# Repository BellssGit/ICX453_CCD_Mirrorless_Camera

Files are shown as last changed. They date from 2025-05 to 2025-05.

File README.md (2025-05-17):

# DIY APS-C Size CCD Sensor Mirrorless Camera



Blog about this project: https://www.emoe.xyz/diy_ccd_camera/ (Chinese)

or https://www.bilibili.com/read/cv41529294/ (Chinese)

## Hardware

1. FPGA Core board --- [Open source ZYNQ7000 Board from oshwhub.com](https://oshwhub.com/z_star/zynq7020-core-board-and-various-rf-modules)
2. CCD Base board --- "CCD_Sensor_ZYNQ_Based_Board" Folder (KiCAD >= 8)
3. Handle and Lens Mount --- "3d_model" Folder (FreeCAD >= 1.0)

## Software

1. "pixel_rearrange.py" for pixel re-arrangement
2. GIMP for gamma correction
3. Fitswork4 for debayer 
4. Photoshop and the "CCD_CameraRAW_Preset" for color grading
5. Vivado 2018.3 and "CCD_Cam_Vivado_workspace.7z" for both PL and PS source code

   Note: Due to Github file size limitation and I dont want to upload the whole workspace folder (because that is a mess), So the workspace is split into two smaller compressed files.

   Update: Just realized I miss a verilog source file "line_skipper.v" which lead to a compile error when generating bitstream. Now the file is in the repo, this is a easy fix. Have fun :)

Some sample photo





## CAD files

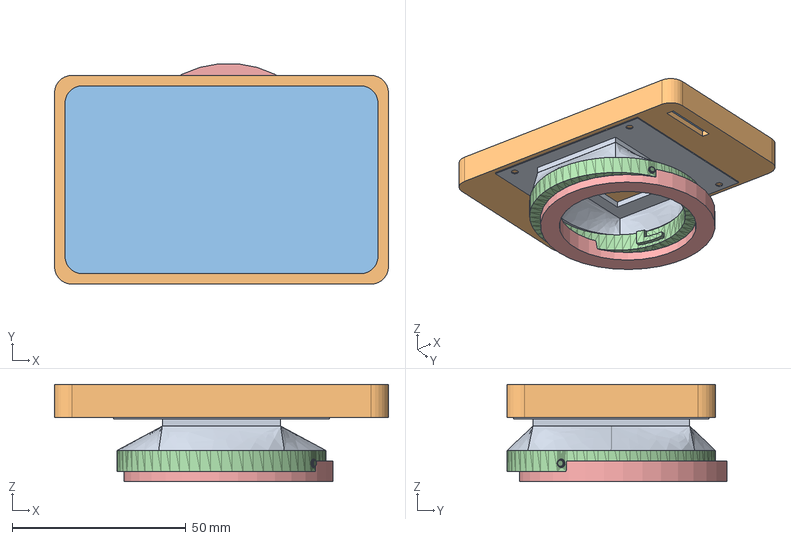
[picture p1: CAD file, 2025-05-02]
3d_model/CCD_Lensmount.FCStd
96.0 x 63.3 x 28.0 mm
top_cover
true_butt
PCB
lens_mount
ring_bump

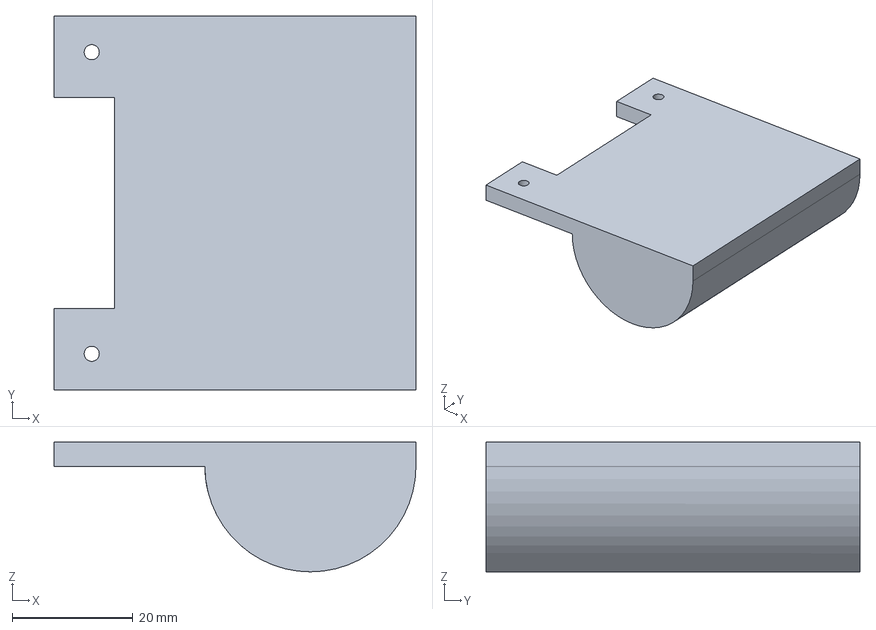
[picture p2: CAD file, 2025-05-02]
3d_model/Hold.FCStd
60.0 x 62.0 x 21.5 mm

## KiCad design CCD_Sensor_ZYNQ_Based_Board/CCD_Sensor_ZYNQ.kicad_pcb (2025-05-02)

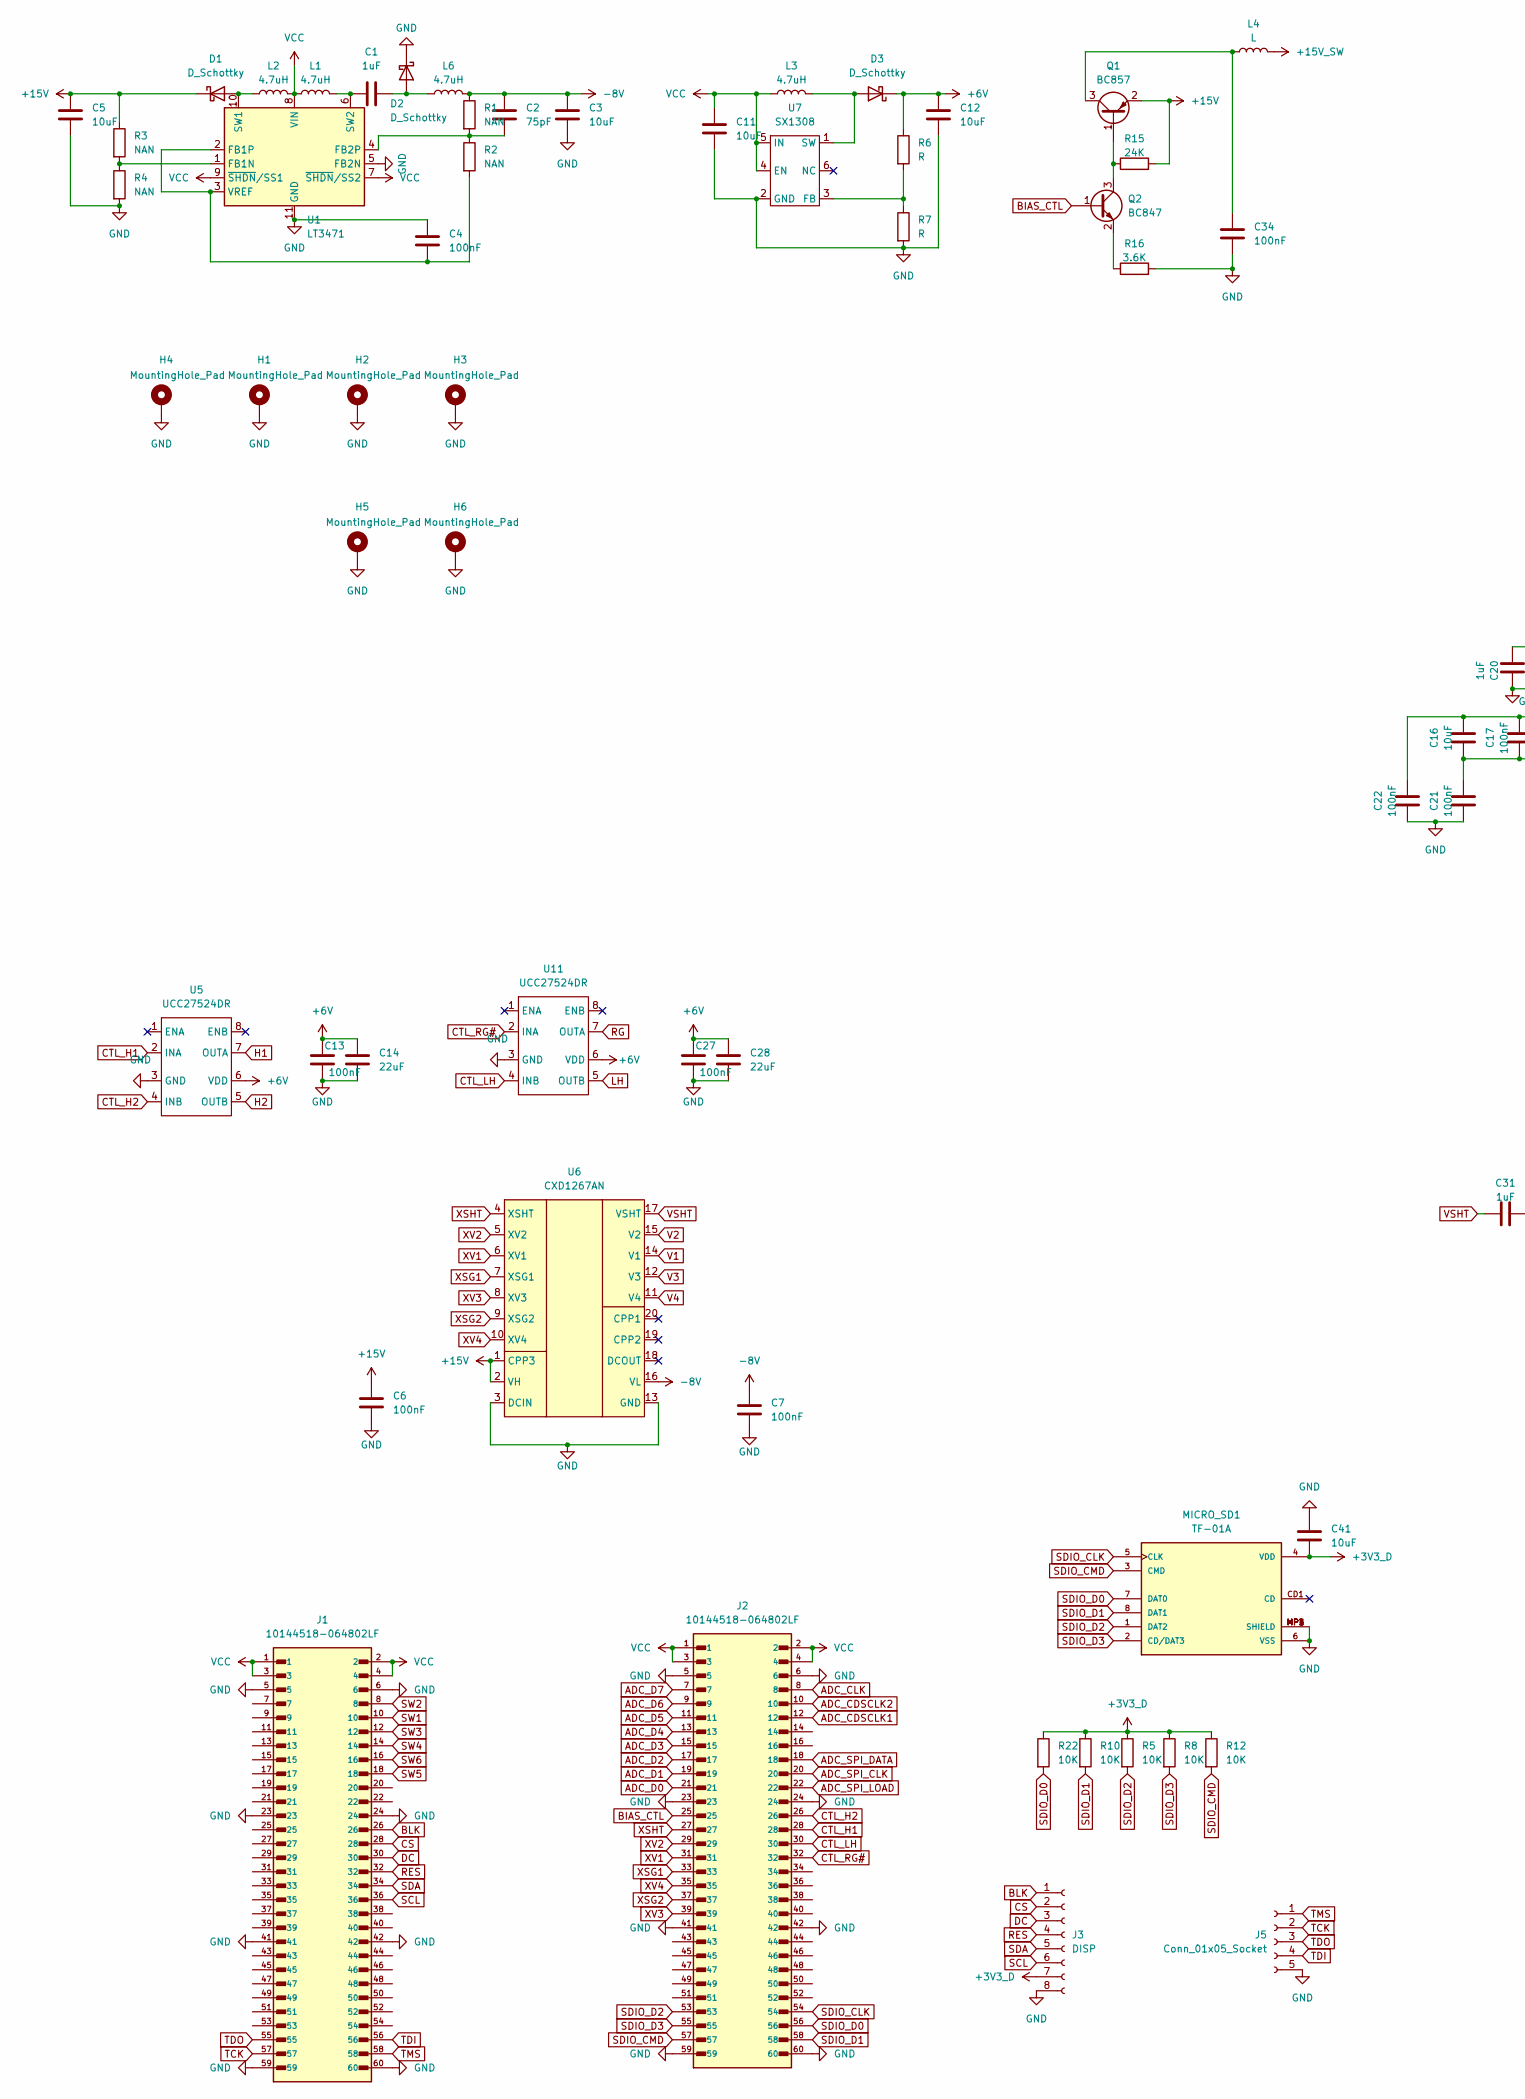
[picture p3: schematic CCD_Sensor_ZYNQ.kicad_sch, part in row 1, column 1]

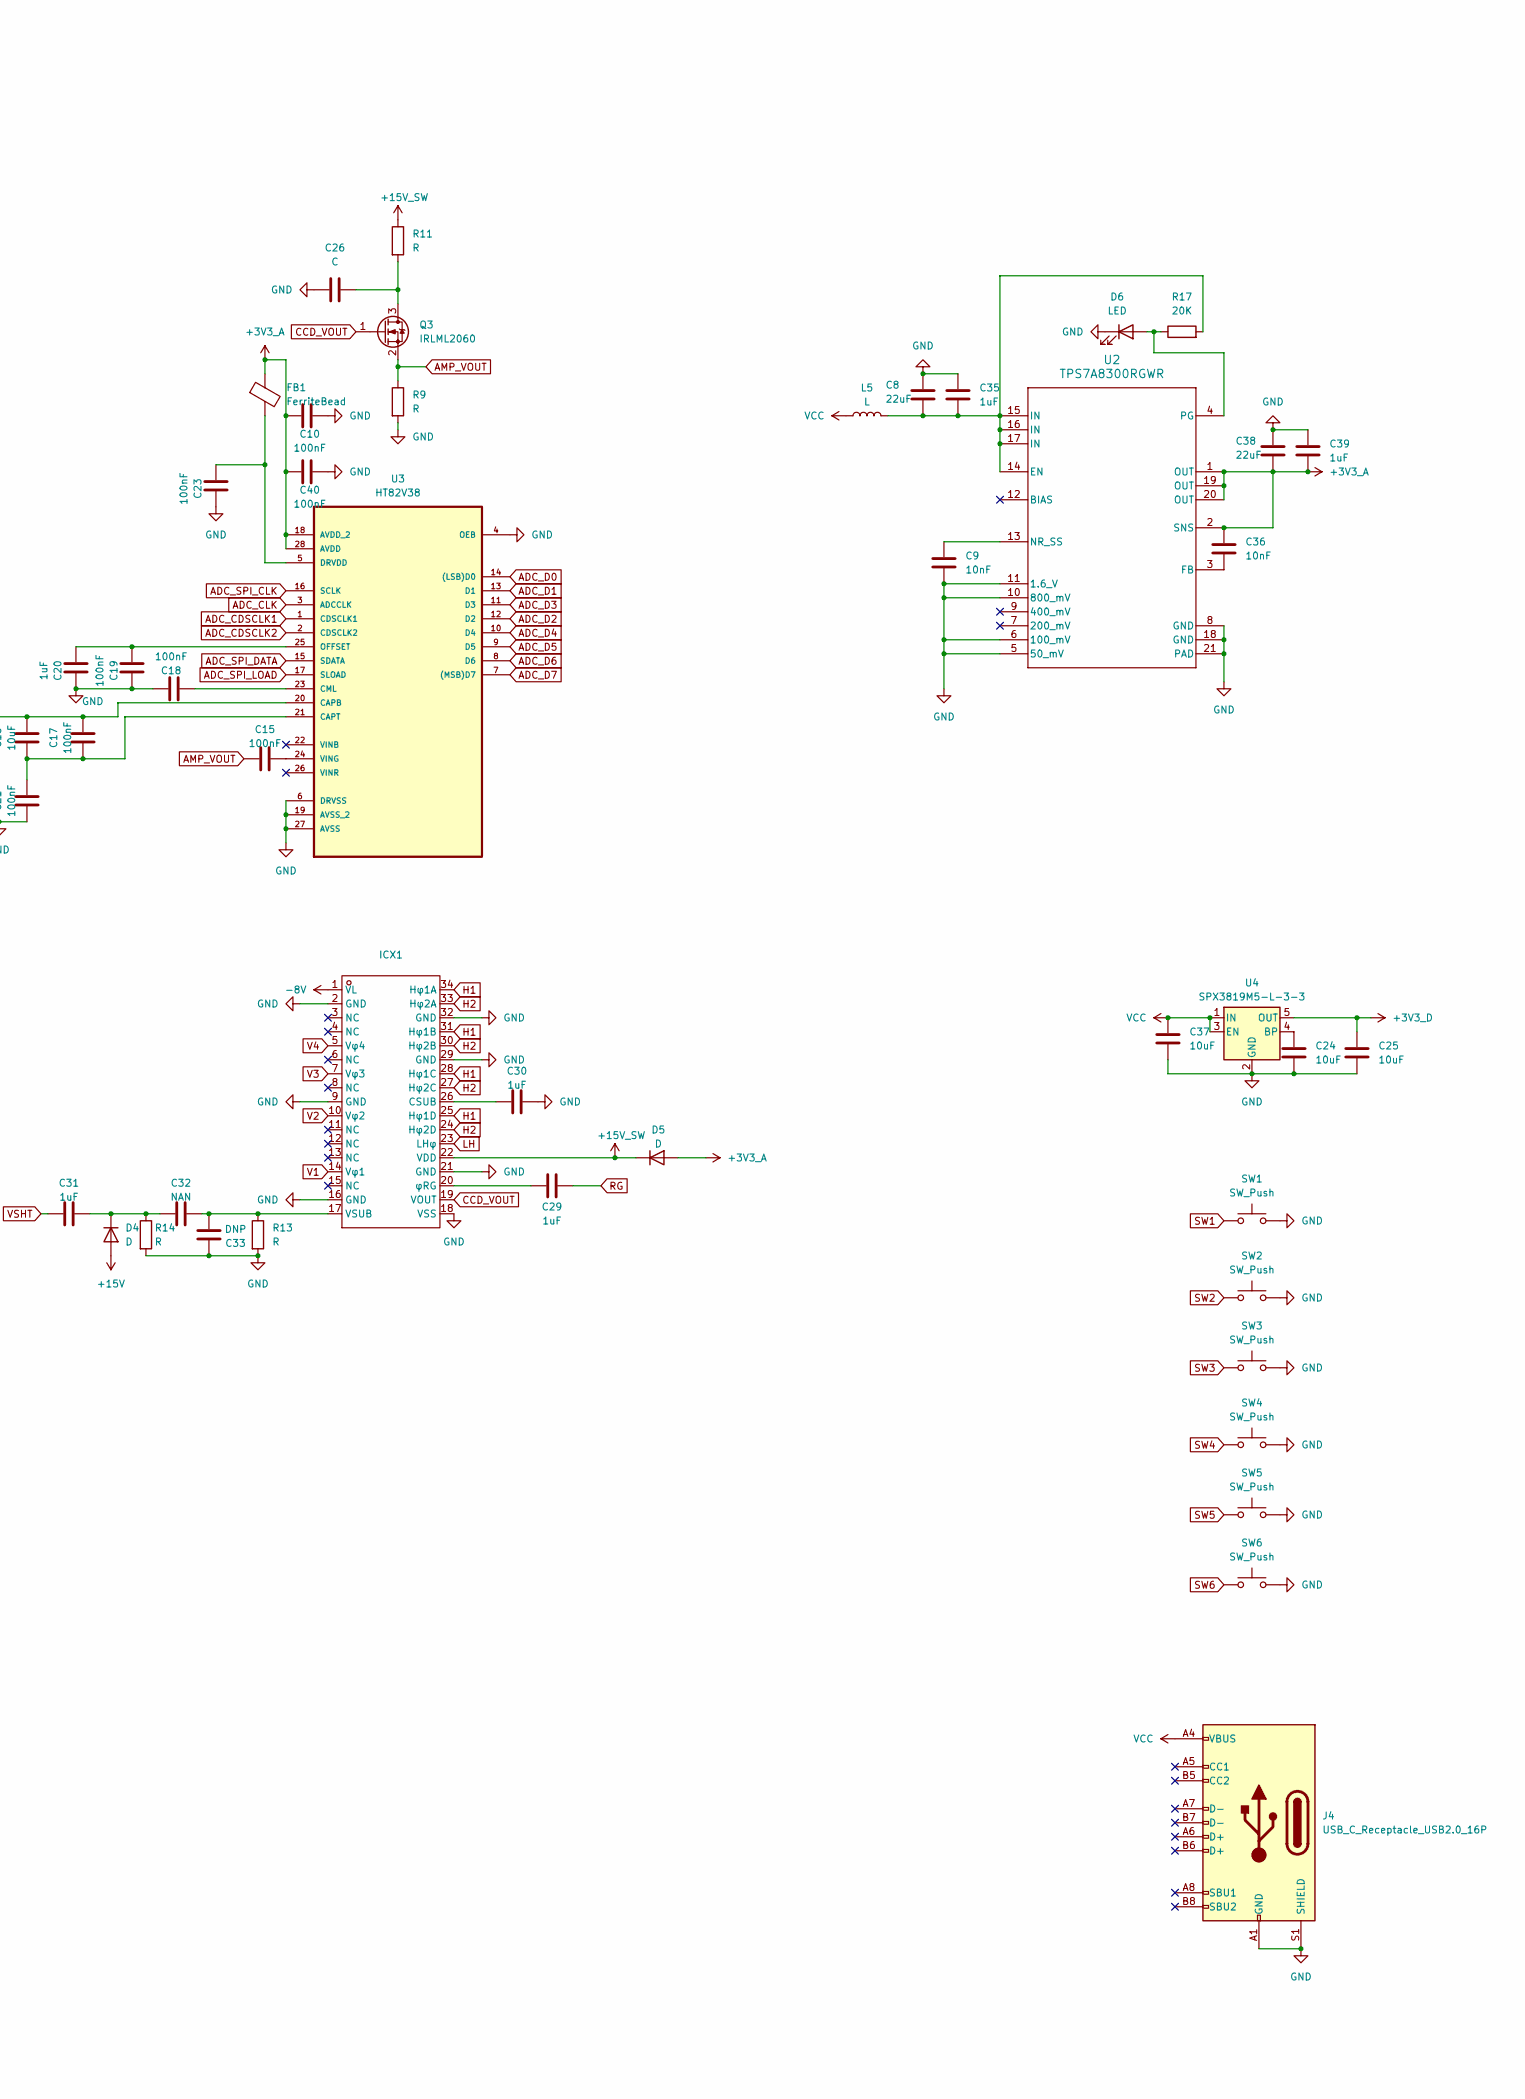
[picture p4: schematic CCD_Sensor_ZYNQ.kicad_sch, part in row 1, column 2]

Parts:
C1: 1uF; C_0603_1608Metric_Pad1.08x0.95mm_HandSolder
C2: 75pF; C_0603_1608Metric_Pad1.08x0.95mm_HandSolder
C3, C5, C12: 10uF; C_0805_2012Metric
C4, C6, C7, C13, C27, C34: 100nF; C_0603_1608Metric_Pad1.08x0.95mm_HandSolder
C8, C38: 22uF; C_0805_2012Metric
C9, C36: 10nF; C_0603_1608Metric
C10, C15, C17, C18, C19, C21, C22, C23, C40: 100nF; C_0603_1608Metric
C11: 10uF; C_0603_1608Metric_Pad1.08x0.95mm_HandSolder
C14, C28: 22uF; C_0805_2012Metric_Pad1.18x1.45mm_HandSolder
C16, C24, C25, C37, C41: 10uF; C_0603_1608Metric
C20, C35, C39: 1uF; C_0603_1608Metric
C26: C; C_0603_1608Metric_Pad1.08x0.95mm_HandSolder
C29, C30, C31: 1uF; C_0805_2012Metric_Pad1.18x1.45mm_HandSolder
C32: NAN; C_0805_2012Metric_Pad1.18x1.45mm_HandSolder
C33: DNP; C_0805_2012Metric_Pad1.18x1.45mm_HandSolder
D1, D2, D3: D_Schottky; D_SOD-123
D4, D5: D; D_SOD-123
D6: LED; LED_0603_1608Metric
FB1: FerriteBead; L_0603_1608Metric
H1, H2, H3, H4, H5, H6: MountingHole_Pad; MountingHole_2.7mm_M2.5_DIN965_Pad
ICX1: DIP-34_1033_ELL
J1, J2: 10144518-064802LF; AMPHENOL_10144518-064802LF; PARTREV H
J3: DISP; PinSocket_1x08_P2.54mm_Vertical
J4: USB_C_Receptacle_USB2.0_16P; USB_C_Receptacle_G-Switch_GT-USB-7010ASV
J5: Conn_01x05_Socket; PinSocket_1x05_P2.54mm_Vertical
L1, L2, L3, L6: 4.7uH; L_Changjiang_FNR252012S
L4: L; L_0603_1608Metric_Pad1.05x0.95mm_HandSolder
L5: L; L_0805_2012Metric
MICRO_SD1: TF-01A
Q1: BC857; SOT-23
Q2: BC847; SOT-23
Q3: IRLML2060; SOT-23
R1, R2, R3, R4: NAN; R_0603_1608Metric
R5, R8, R10, R12, R22: 10K; R_0603_1608Metric
R6, R7, R13, R14: R; R_0603_1608Metric_Pad0.98x0.95mm_HandSolder
R9, R11: R; R_0603_1608Metric
R15: 24K; R_0603_1608Metric_Pad0.98x0.95mm_HandSolder
R16: 3.6K; R_0603_1608Metric_Pad0.98x0.95mm_HandSolder
R17: 20K; R_0603_1608Metric
SW1, SW2, SW3, SW4, SW5, SW6: SW_Push; SW_SPST_PTS645
U1: LT3471; DFN-10-1EP_3x3mm_P0.5mm_EP1.65x2.38mm
U2: TPS7A8300RGWR; RGW0020A
U3: HT82V38; SSOP-28_5.3x10.2mm_P0.65mm; MPN AD9826KRSZ
U4: SPX3819M5-L-3-3; SOT-23-5
U5, U11: UCC27524DR; SOIC-8_3.9x4.9mm_P1.27mm
U6: CXD1267AN; TSSOP-20_4.4x6.5mm_P0.65mm
U7: SX1308; SOT-23-6

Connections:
+3V3_A: C10.1, C36.1, C38.2, C39.2, C40.1, D5.2 (A), FB1.1, U2.1 (OUT), U2.2 (SNS), U2.19 (OUT), U2.20 (OUT), U3.18 (AVDD_2), U3.28 (AVDD)
+3V3_D: C25.1, C41.2, J3.7, MICRO_SD1.4 (VDD), R5.1, R8.1, R10.1, R12.1, R22.1, U4.5 (OUT)
+6V: C12.1, C13.1, C14.1, C27.1, C28.1, D3.1 (K), R6.1, U5.6 (VDD), U11.6 (VDD)
+15V: C5.1, C6.1, D1.1 (K), D4.2 (A), Q1.2 (E), R3.1, R15.2, U6.1 (CPP3), U6.2 (VH)
+15V_SW: D5.1 (K), ICX1.22 (VDD), L4.2, R11.1
-8V: C2.2, C3.1, C7.1, ICX1.1 (VL), L6.2, R1.1, U6.16 (VL)
ADC_CDSCLK1: J2.12, U3.1 (CDSCLK1)
ADC_CDSCLK2: J2.10, U3.2 (CDSCLK2)
ADC_CLK: J2.8, U3.3 (ADCCLK)
ADC_D0: J2.21, U3.14 ((LSB)D0)
ADC_D1: J2.19, U3.13 (D1)
ADC_D2: J2.17, U3.12 (D2)
ADC_D3: J2.15, U3.11 (D3)
ADC_D4: J2.13, U3.10 (D4)
ADC_D5: J2.11, U3.9 (D5)
ADC_D6: J2.9, U3.8 (D6)
ADC_D7: J2.7, U3.7 ((MSB)D7)
ADC_SPI_CLK: J2.20, U3.16 (SCLK)
ADC_SPI_DATA: J2.18, U3.15 (SDATA)
ADC_SPI_LOAD: J2.22, U3.17 (SLOAD)
AMP_VOUT: C15.1, Q3.2 (S), R9.1
BIAS_CTL: J2.25, Q2.1 (B)
BLK: J1.26, J3.1
CCD_VOUT: ICX1.19 (VOUT), Q3.1 (G)
CS: J1.28, J3.2
CTL_H1: J2.28, U5.2 (INA)
CTL_H2: J2.26, U5.4 (INB)
CTL_LH: J2.30, U11.4 (INB)
CTL_RG#: J2.32, U11.2 (INA)
DC: J1.30, J3.3
GND: C3.2, C4.2, C5.2, C6.2, C7.2, C8.1, C9.2, C10.2, C11.2, C12.2, C13.2, C14.2, C18.2, C19.2, C20.2, C21.1, C22.1, C23.2, C24.2, C25.2, C26.1, C27.2, C28.2, C30.2, C33.1, C34.2, C35.1, C37.2, C38.1, C39.1, C40.2, C41.1, D2.1 (K), D6.1 (K), H1.1, H2.1, H3.1, H4.1, H5.1, H6.1, ICX1.2 (GND), ICX1.9 (GND), ICX1.16 (GND), ICX1.18 (VSS), ICX1.21 (GND), ICX1.29 (GND), ICX1.32 (GND), J1.5, J1.6, J1.23, J1.24, J1.41, J1.42, J1.59, J1.60, J2.5, J2.6, J2.23, J2.24, J2.41, J2.42, J2.59, J2.60, J3.8, J4.A1 (GND), J4.A12 (GND), J4.B1 (GND), J4.B12 (GND), J4.S1 (SHIELD), J5.5, MICRO_SD1.6 (VSS), MICRO_SD1.MP1 (SHIELD), MICRO_SD1.MP2 (SHIELD), MICRO_SD1.MP3 (SHIELD), MICRO_SD1.MP4 (SHIELD), R4.2, R7.2, R9.2, R13.2, R14.2, R16.2, SW1.2, SW2.2, SW3.2, SW4.2, SW5.2, SW6.2, U1.5 (FB2N), U1.11 (GND), U2.5 (50_mV), U2.6 (100_mV), U2.8 (GND), U2.10 (800_mV), U2.11 (1.6_V), U2.18 (GND), U2.21 (PAD), U3.4 (OEB), U3.6 (DRVSS), U3.19 (AVSS_2), U3.27 (AVSS), U4.2 (GND), U5.3 (GND), U6.3 (DCIN), U6.13 (GND), U7.2 (GND), U11.3 (GND)
H1: ICX1.25 (Hφ1D), ICX1.28 (Hφ1C), ICX1.31 (Hφ1B), ICX1.34 (Hφ1A), U5.7 (OUTA)
H2: ICX1.24 (Hφ2D), ICX1.27 (Hφ2C), ICX1.30 (Hφ2B), ICX1.33 (Hφ2A), U5.5 (OUTB)
LH: ICX1.23 (LHφ), U11.5 (OUTB)
unnamed: D1.2 (A), L2.1, U1.10 (SW1)
unnamed: C1.2, D2.2 (A), L6.1
unnamed: D3.2 (A), L3.2, U7.1 (SW)
unnamed: C31.2, C32.1, D4.1 (K), R14.1
unnamed: D6.2 (A), R17.1, U2.4 (PG)
unnamed: C30.1, ICX1.26 (CSUB)
unnamed: C32.2, C33.2, ICX1.17 (VSUB), R13.1
unnamed: C29.1, ICX1.20 (φRG)
unnamed: Q1.1 (B), Q2.3 (C), R15.1
unnamed: C34.1, L4.1, Q1.3 (C)
unnamed: Q2.2 (E), R16.1
unnamed: C26.2, Q3.3 (D), R11.2
unnamed: R3.2, R4.1, U1.1 (FB1N)
unnamed: C4.1, R2.2, U1.2 (FB1P), U1.3 (VREF)
unnamed: C2.1, R1.2, R2.1, U1.4 (FB2P)
unnamed: C1.1, L1.2, U1.6 (SW2)
unnamed: C8.2, C35.2, L5.2, R17.2, U2.14 (EN), U2.15 (IN), U2.16 (IN), U2.17 (IN)
unnamed: C36.2, U2.3 (FB)
unnamed: C9.1, U2.13 (NR_SS)
unnamed: C16.2, C17.2, C22.2, U3.20 (CAPB)
unnamed: C16.1, C17.1, C21.2, U3.21 (CAPT)
unnamed: C18.1, U3.23 (CML)
unnamed: C23.1, FB1.2, U3.5 (DRVDD)
unnamed: C19.1, C20.1, U3.25 (OFFSET)
unnamed: C15.2, U3.24 (VING)
unnamed: C24.1, U4.4 (BP)
unnamed: R6.2, R7.1, U7.3 (FB)
RES: J1.32, J3.4
RG: C29.2, U11.7 (OUTA)
SCL: J1.36, J3.6
SDA: J1.34, J3.5
SDIO_CLK: J2.54, MICRO_SD1.5 (CLK)
SDIO_CMD: J2.57, MICRO_SD1.3 (CMD), R12.2
SDIO_D0: J2.56, MICRO_SD1.7 (DAT0), R22.2
SDIO_D1: J2.58, MICRO_SD1.8 (DAT1), R10.2
SDIO_D2: J2.53, MICRO_SD1.1 (DAT2), R5.2
SDIO_D3: J2.55, MICRO_SD1.2 (CD/DAT3), R8.2
SW1: J1.10, SW1.1
SW2: J1.8, SW2.1
SW3: J1.12, SW3.1
SW4: J1.14, SW4.1
SW5: J1.18, SW5.1
SW6: J1.16, SW6.1
TCK: J1.57, J5.2
TDI: J1.56, J5.4
TDO: J1.55, J5.3
TMS: J1.58, J5.1
V1: ICX1.14 (Vφ1), U6.14 (V1)
V2: ICX1.10 (Vφ2), U6.15 (V2)
V3: ICX1.7 (Vφ3), U6.12 (V3)
V4: ICX1.5 (Vφ4), U6.11 (V4)
VCC: C11.1, C37.1, J1.1, J1.2, J1.3, J1.4, J2.1, J2.2, J2.3, J2.4, J4.A4 (VBUS), J4.A9 (VBUS), J4.B4 (VBUS), J4.B9 (VBUS), L1.1, L2.2, L3.1, L5.1, U1.7 (~SHDN/SS2), U1.8 (VIN), U1.9 (~SHDN/SS1), U4.1 (IN), U4.3 (EN), U7.4 (EN), U7.5 (IN)
VSHT: C31.1, U6.17 (VSHT)
XSG1: J2.33, U6.7 (XSG1)
XSG2: J2.37, U6.9 (XSG2)
XSHT: J2.27, U6.4 (XSHT)
XV1: J2.31, U6.6 (XV1)
XV2: J2.29, U6.5 (XV2)
XV3: J2.39, U6.8 (XV3)
XV4: J2.35, U6.10 (XV4)

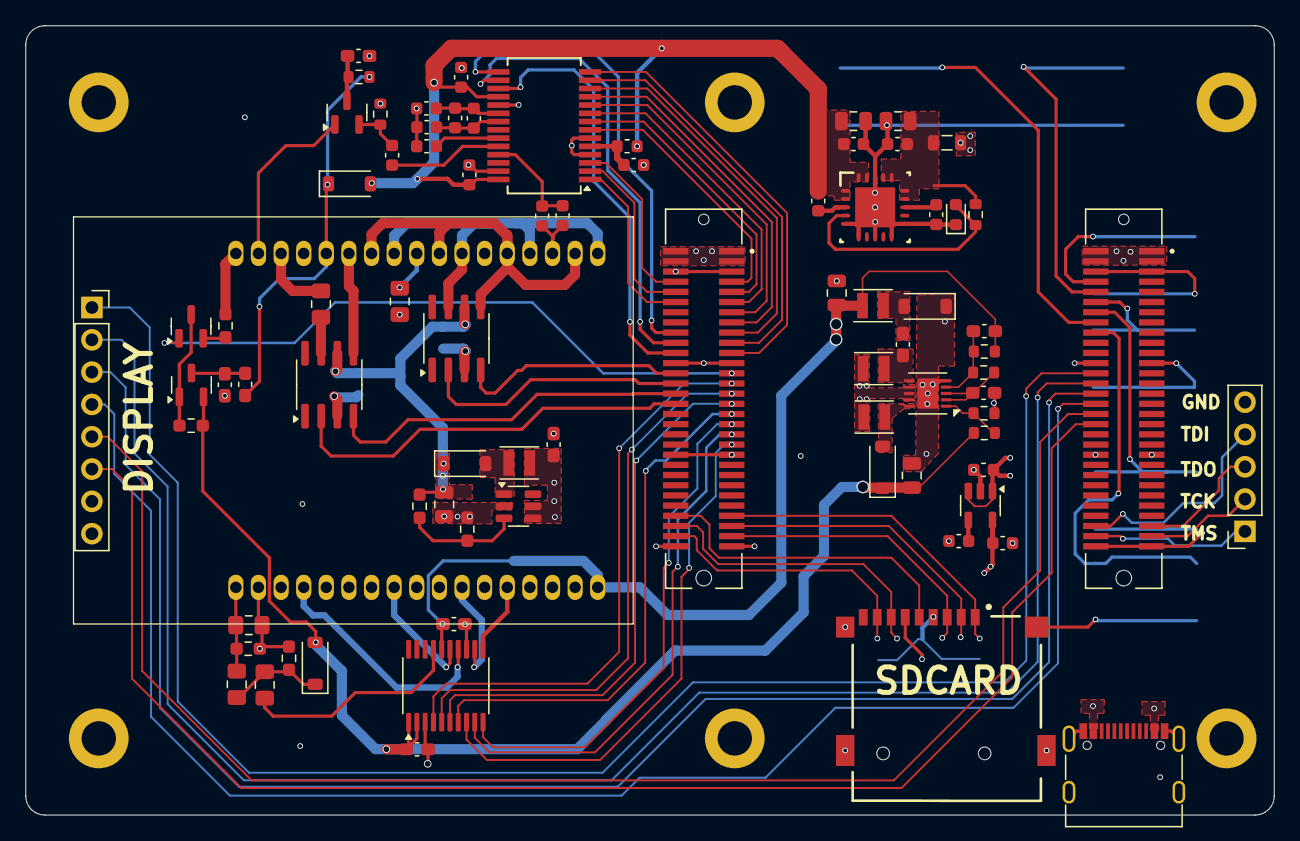
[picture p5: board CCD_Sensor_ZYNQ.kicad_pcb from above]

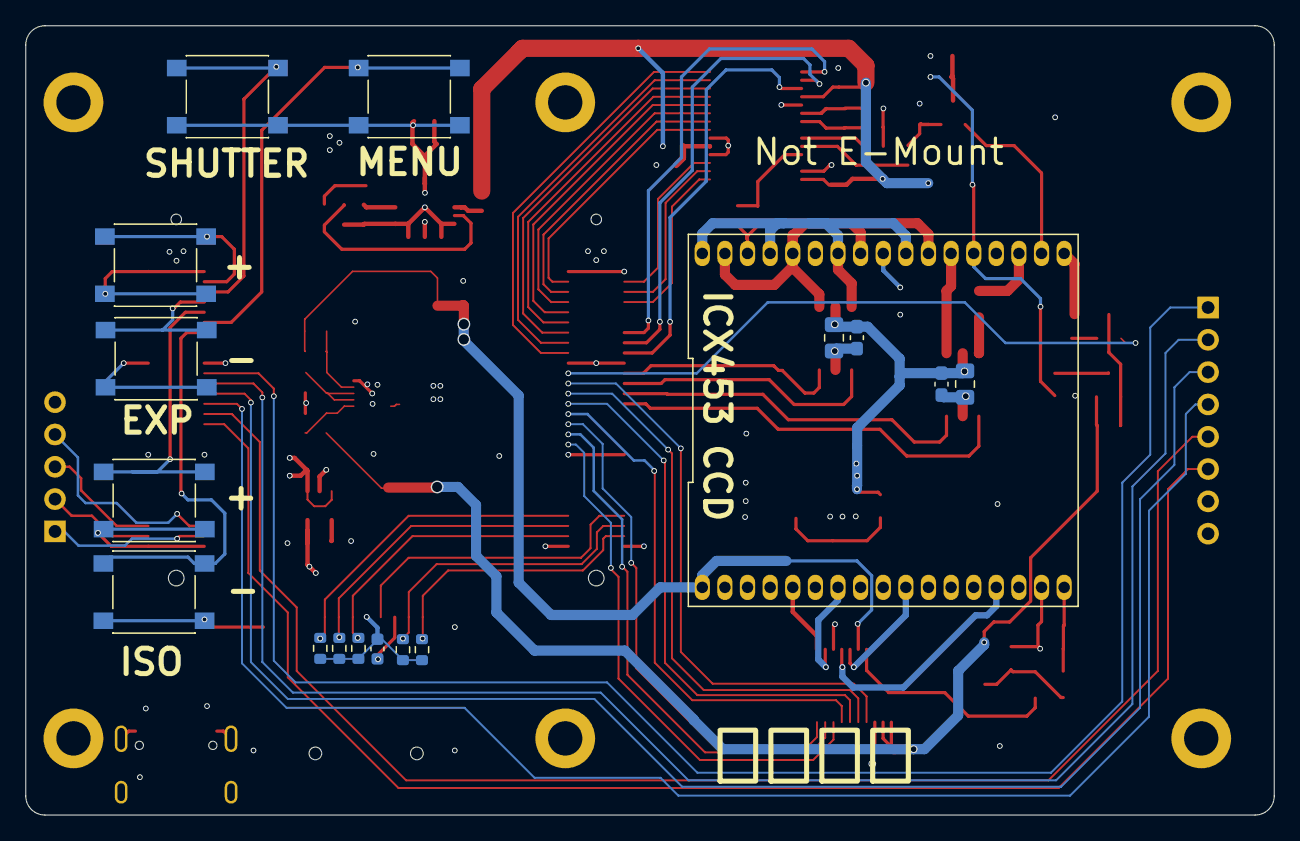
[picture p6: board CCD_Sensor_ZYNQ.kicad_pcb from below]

Board: 4 copper layers, 98.1 x 62.1 mm, 102 parts (17 on the bottom side), 94 nets.
